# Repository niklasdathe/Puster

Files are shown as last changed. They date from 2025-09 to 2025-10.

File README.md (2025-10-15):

# Puster
## motivation  

I’ve been struggling with a light dust mite allergiy for years, so clean indoor air is more than just a comfort—it’s a necessity. Dust mites thrive in humid environments, and their microscopic waste is causing sneezing, itchy eyes and concentration problems. Since people spend over 90% of their time indoors, where pollutant concentrations can be two to five times higher than outdoors, the quality of indoor air has a huge influence on health (Morantes et al., *Environmental Science & Technology*, 2023; Sensirion, *Improving Indoor Air Quality*, 2023).  

Research shows that three pollutants—particulate matter most (PM2.5 and PM10), formaldehyde, and nitrogen dioxide—account for almost all of the chronic harm caused by typical indoor contaminants. Together they make up nearly 99% of the total health burden, with particulate matter alone responsible for more than 90% of the impact (Morantes et al., 2023). Poor indoor air quality is not only linked to allergies and asthma but also to reduced cognitive performance, sleep disruption, and higher risks of cardiovascular disease (Allen et al., *Environmental Health Perspectives*, 2015; Kang et al., *Building and Environment*, 2023).  

A standard HEPA filter like the one in Puster cannot remove everything, but it is very effective at capturing fine and coarse particles—including PM2.5, PM10, pollen, mold spores, and dust mite debris. This directly addresses the single most harmful category of indoor air pollutants. For the others, different strategies are needed:  

By focusing on HEPA particle filtration, Puster directly reduces the largest share of harm from indoor air pollution, while also lowering exposure to common allergens. Combined with sensible source control and optional add-ons like activated carbon, it offers a practical and flexible way to improve indoor air where it matters most.  

---

### what HEPA filters and what to add for the rest  

| Pollutant | Health effects | HEPA effective? | Remedies / add-ons |
|---|---|---|---|
| **PM2.5 / PM10** | Major cause of heart & lung disease, >90% of total harm. | ✅ Yes | Run HEPA Puster; boost during spikes (e.g., cooking, smoke); automate with Riecher. |
| **Pollen & dust mites** | Allergy & asthma triggers; mites thrive in humidity. | ✅ Yes | Keep RH ~40–60%; encase bedding; HEPA vacuuming. |
| **Mold spores** | Allergies, asthma, irritation. | ✅ Yes | Fix moisture issues; dehumidify; clean visible mold. |
| **NO₂** | Lung damage, asthma, heart risks. | ❌ No | Use induction/vented cooking; add carbon/chemisorbent filter. |
| **Formaldehyde** | Carcinogen, eye/lung irritant. | ❌ No | Avoid high-emitting materials. |
| **O₃** | Worsens asthma, lung irritation. | ❌ No | Avoid ozone devices; add carbon/MnO₂ media; ventilate when outdoor O₃ is low. |
| **VOCs** | Headaches, irritation; some are carcinogenic. | ❌ No | Source control + ventilation; thick carbon filter, replace often. |
| **Radon** | Second leading cause of lung cancer. | ❌ No | Building mitigation. |
| **CO₂** | Reduces cognition & sleep quality. | ❌ No | Ventilation; demand-control with CO₂ sensor (e.g., Riecher). |

---

**Key references for context:**  
- Morantes, G., Jones, B., Molina, C., & Sherman, M. H. (2023). *Harm from Residential Indoor Air Contaminants*. Environmental Science & Technology, 58(1), 242–257.  
- WHO Guideline for Formaldehyde: 0.1 mg/m³ (80 ppb) over 30 minutes.  
- Allen, J. G., et al. (2015). *Environmental Health Perspectives*. Cognitive decline with poor IAQ.  
- Kang, M., et al. (2023). *Building and Environment*. CO₂ impact on sleep quality.  
- Sensirion (2023). *Improving Indoor Air Quality* brochure.  

## mechanicals
### parts list
- **1x FY0194/30 (for phillips 800 series)**  
  widely available through many different sources 
- **1x ESP32C6 based PCB**  
  More infos/files can be found in /electronics/  
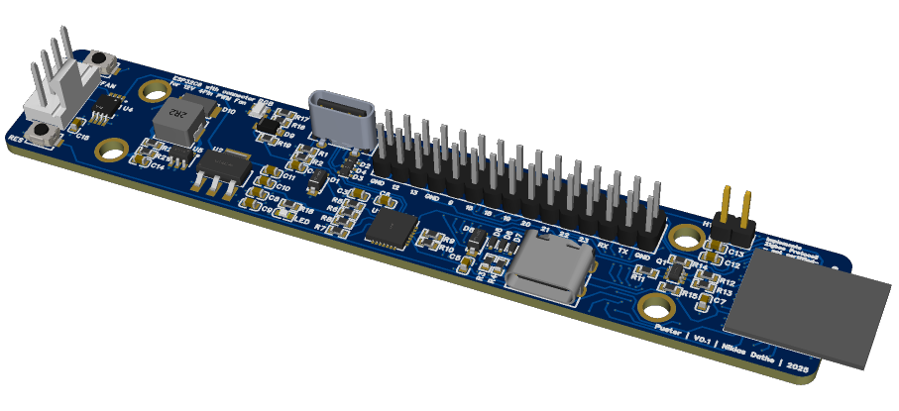
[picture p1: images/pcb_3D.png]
    
- **1x USB-C cable for powering the Puster**  
  this needs to be quite long as it acts as the power cable  
  also used to flash the firmware  
- **1x 4-Pin 12V PWM Fan**  
  i used a noctua fan as they are well built, quite and the color scheme suits my version of Puster  
- **1x base**  
  I routed mine out of reclaimed bankirai wood but you could also print this.  
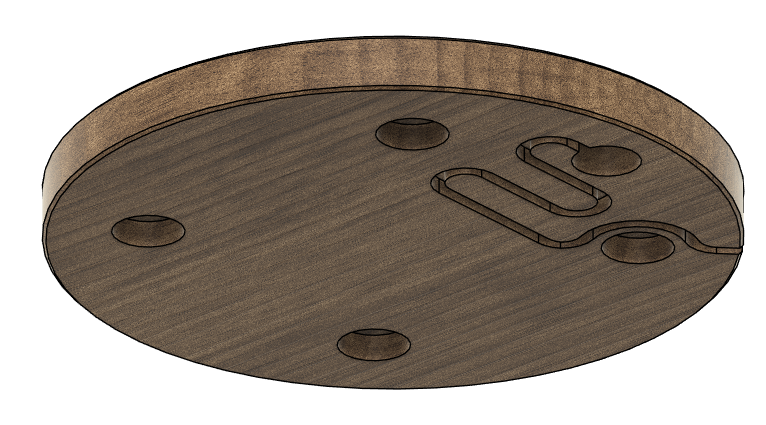
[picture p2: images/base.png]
    
- **1x lid**  
  3D printed out wood-filled-filament but you can use whatever filament you like. Feel free to get creative.:)  
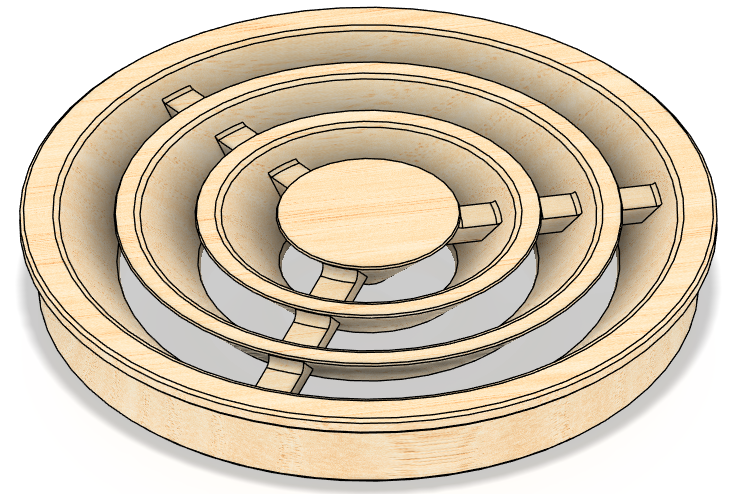
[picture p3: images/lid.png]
    
- **1x cage**  
  3D printed out wood-filled-filament but you can use whatever filament you like. Feel free to get creative.:)  
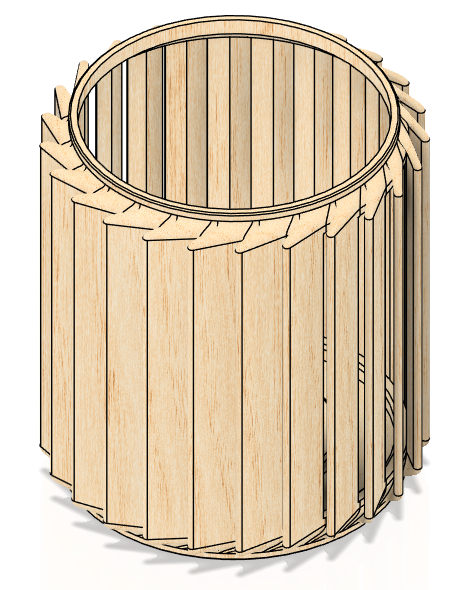
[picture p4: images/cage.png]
    
- **1x adapter**  
  3D printed out wood-filled-filament but you can use whatever filament you like. Feel free to get creative.:)  
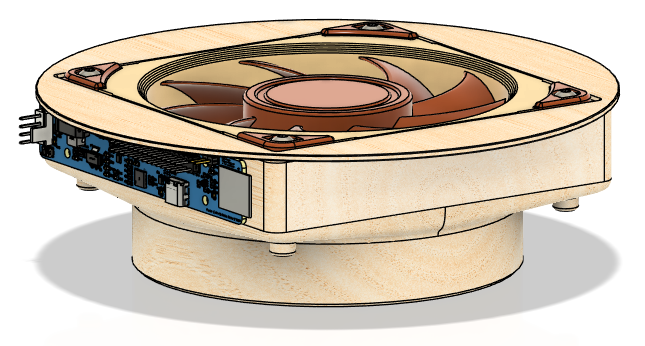
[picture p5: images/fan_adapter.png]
    
- **4x rubber feet**  
  these could easily be 3d printed but i used off the shelf parts i had laying around  
  [20mm diameter, 12mm height, 4mm thorugh hole]  
- _x screws
  TODO

### manufacturing

The ***base*** was routed from wood using a cnc machine. This was a dual sided operation as it has features on both sides of the base. On the bottom there is a place for the cable to be routed which acts as a strain relief at the same time. The base is attached to the cage with 4 M4 bolts that also hold the feet in place. I decided against the single responsiblilty idea for simplicity reasons.  
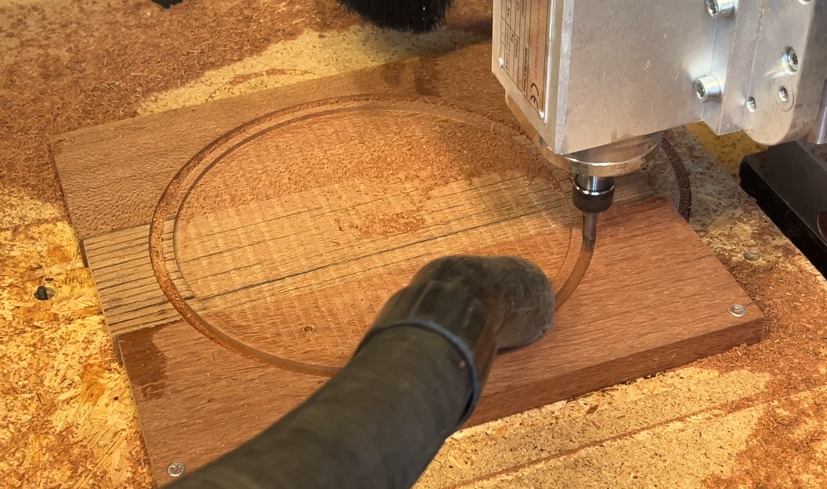
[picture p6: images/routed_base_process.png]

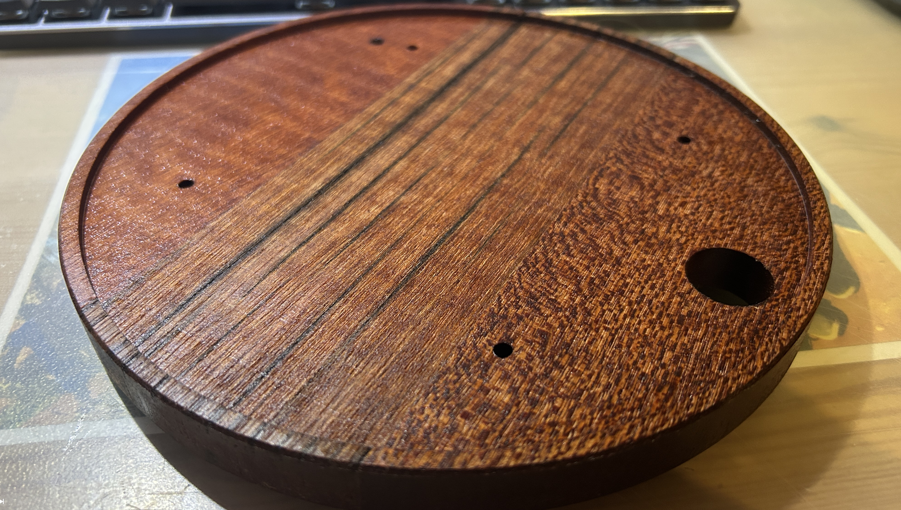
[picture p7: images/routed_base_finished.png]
  
The ***cage*** was printed with Bambu Labs wood filament. It just fits on my P1S. On the 0.3mm layer height preset with a 0.6mm nozzle, the print took 12 hours. On my usual preset it would've taken 41 hours.  

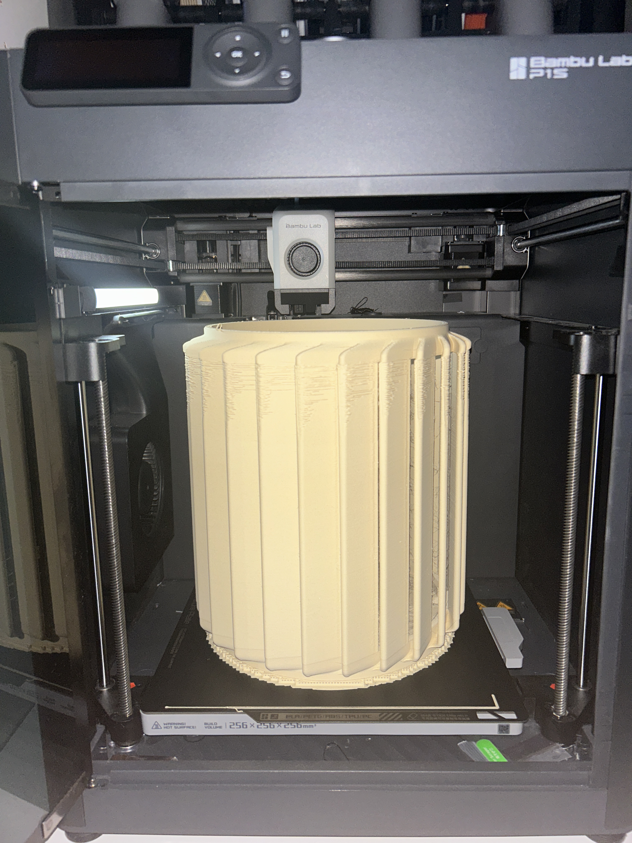
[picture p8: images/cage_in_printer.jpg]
  

On my version the print got quite a lot of defects near the top of the print which happended because the vertical slats were unsupported and flexing substantially due to the printing forces. This is mitigated in the current version by added cross braces. Also, the top opening was slightly too small which was also reworked in the second revision. 

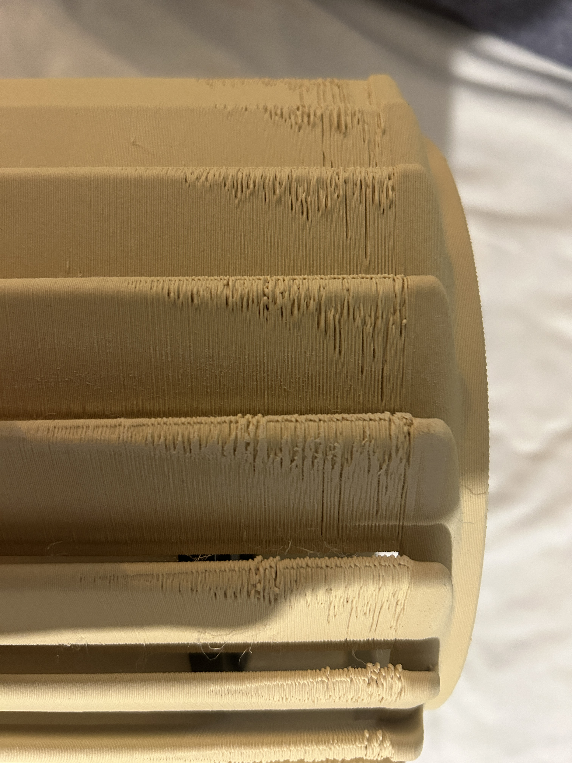
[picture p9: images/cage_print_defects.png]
  

The ***lid*** was also printed from the same filament. This took just 4 hours.

The ***adapter*** was also printed in this filament for consistency reasons. Here I didnt get around using support structures but with a well tuned preset, they were easily removed.

## electronics
### the pcb 
you can order the pcb through the following link:  
https://aisler.net/p/XLGCRZIT  
i added a stencil to help me with assembly.

the ESP32-C6 was chosen as the core of the Puster PCB because it offers modern wireless connectivity while staying flexible for different smart home ecosystems. with support for Wi-Fi 6, Bluetooth Low Energy 5.0, Zigbee and Thread (Matter), it can easily integrate into existing setups, whether that’s a Zigbee network, Matter-over-Thread, or simple Wi-Fi control. this makes the device adaptable for the future without locking it to one protocol.

for fan control, I used the EMC2101, a dedicated I²C fan controller. this chip simplifies reliable 4-pin PWM fan operation by:  

- generating the Intel-spec compliant PWM signal.
- monitoring the fan tachometer feedback for RPM validation.
- allowing precise control of fan speed directly over the I²C bus.

by offloading the fan PWM and tachometer handling to the EMC2101, the ESP32-C6 remains free for wireless communication and higher-level logic. this approach ensures smooth and safe operation of 12V PC-style fans without risking glitches or timing issues from software-driven PWM and tacho pulse counting.  

I also brought out the full GPIO Header known from the ESP32 Devkits which allows the Puster to be extended to your liking. 

routing turned out to be quite the challenge as the board is only 2cm wide but i managed to somehow squeeze it all in:  
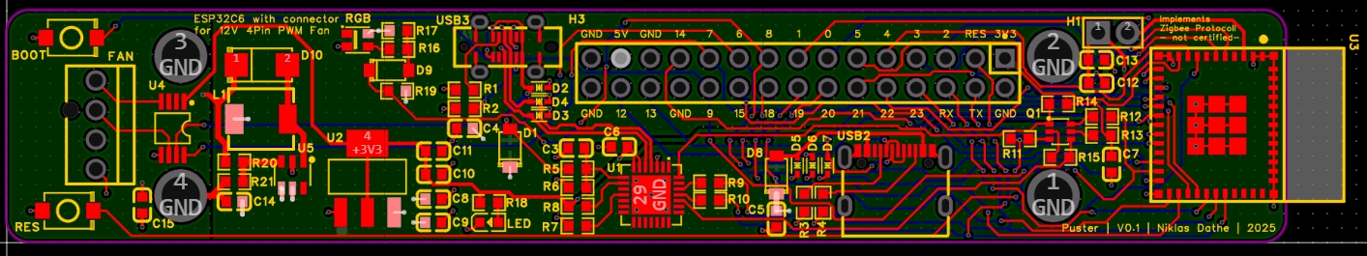
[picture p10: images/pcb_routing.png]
   
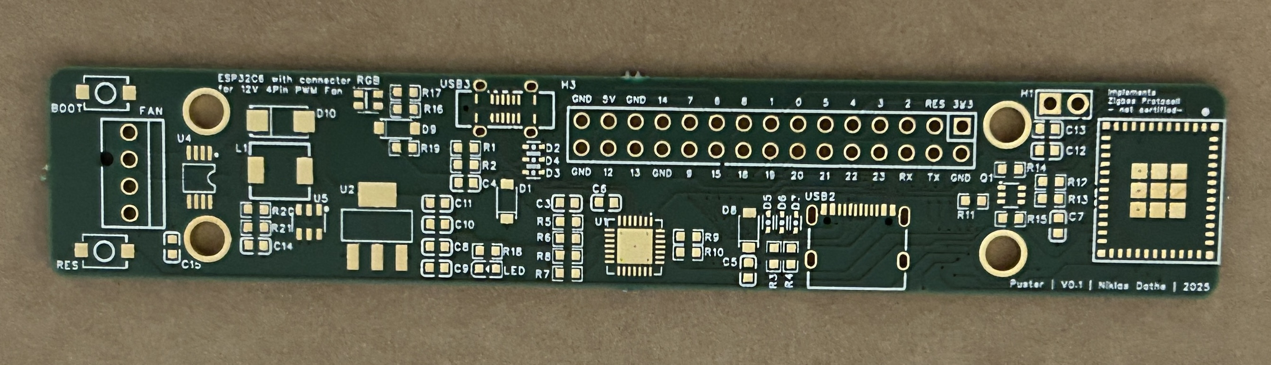
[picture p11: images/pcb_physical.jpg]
   
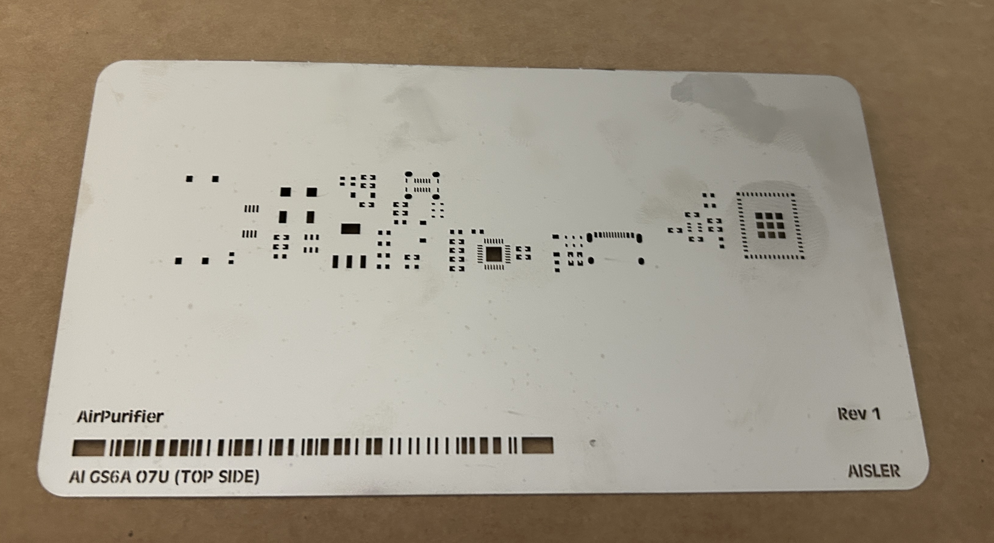
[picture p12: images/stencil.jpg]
   

### assembly 
TODO - pictures of my assembly process
### testing
TODO -pictures of pcb testing

### the fan
the pcb was built around this type of fan connector(TODO specific kind):  

(from Noctua PWM specifications 
white paper)

*Its important that only 12V fans are used, as other fans might get damaged by being overvolted.*

the pwm lines are driven at 5V, as per intel specification  

## software
## zigbee setup
With the current configuration this device acts as a zigbee router. THat means it will extend your zigbee mesh. I decided to this because I don't have tight power constraints as its plugged into the wall.   

   

the Zigbee data model is set up in a way, that the tachometer data (actual fan rpm) can be read from the device over Zigbee and the fan pmw (desired fan rpm) can be set over Zigbee. I haven't tried this yet but you might be able to close the control loop with this.  
TODO. actual cLuster/endpoint architecture

  

### why zigbee?
That decision was simple, i already had a working zigbee mesh network. I've been interested in Matter over Thread lately but thats a story for another time.

*im sure its easily adapted to matter over thread, wifi or whatever other radio protocolls your using in your smarthome*

### pairing
TODO

### resetting
TODO

### integration with homeassitant (zigbee2mqtt)
TODO

### flashing custom firmware
TODO - which port to use, links to implementation help/wikis
If anyone adapts this to other protocolls, feel free to share it so other people can benfit too

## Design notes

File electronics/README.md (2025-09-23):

This folder contains everything related to the PCB 

Link to the Aisler Project through which you can order the board:  
https://aisler.net/p/XLGCRZIT (you might want to order a stencil too, as I'm using 0603 components)

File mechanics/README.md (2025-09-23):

this folder contains all the files for the mechanical assembly

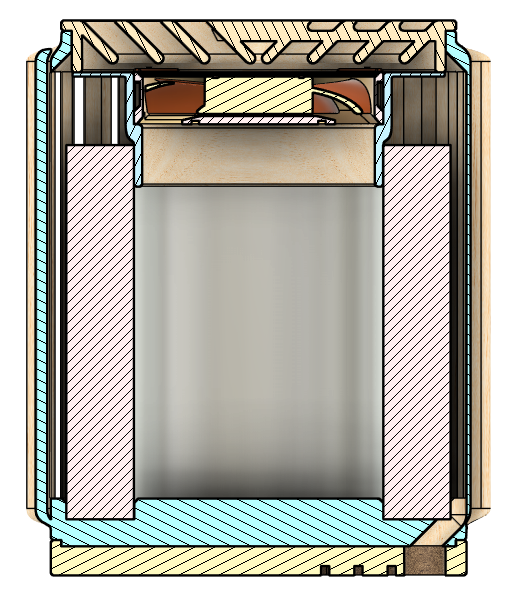
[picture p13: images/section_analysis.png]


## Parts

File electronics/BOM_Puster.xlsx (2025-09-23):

No. | Quantity | Comment | Designator | Footprint | Value | Manufacturer Part | Manufacturer | Supplier Part | Supplier | Add into BOM
1 | 2 | TS-1088-AR02016 | BOOT,RES | SW-SMD_L3.9-W3.0-P4.45 |  | TS-1088-AR02016 | XUNPU(讯普) | C720477 | LCSC | yes
2 | 1 | 1uF | C3 | C0603 | 1uF | CL10A105KB8NNNC | SAMSUNG(三星) | C15849 | LCSC | yes
3 | 8 | 10uF | C4,C5,C6,C8,C10,C12,C14,C15 | C0603 | 10uF | CL10A106MQ8NNNC | SAMSUNG(三星) | C1691 | LCSC | yes
4 | 1 | DNP | C7 | C0603 | 1uF | CL10A105KB8NNNC | SAMSUNG(三星) | C15849 | LCSC | yes
5 | 3 | 100nF | C9,C11,C13 | C0603 | 100nF | CC0603KRX7R9BB104 | YAGEO(国巨) | C14663 | LCSC | yes
6 | 2 | 1N5819HW-7-F | D1,D8 | SOD-123_L2.7-W1.6-LS3.7-RD |  | 1N5819HW-7-F | DIODES(美台) | C82544 | LCSC | yes
7 | 6 | LESD5D5.0CT1G | D2,D3,D4,D5,D6,D7 | SOD-523_L1.2-W0.8-LS1.6-BI |  | LESD5D5.0CT1G | UMW(友台半导体) | C5199850 | LCSC | yes
8 | 1 | 1N4148W | D9 | SOD-123_L2.8-W1.8-LS3.7-RD-1 |  | 1N4148W | JSMSEMI(杰盛微) | C917030 | LCSC | yes
9 | 1 | SS34 | D10 | SMA_L4.3-W2.6-LS5.2-RD |  | SS34 | MDD(辰达半导体) | C8678 | LCSC | yes
10 | 1 | 470531000 | FAN | CONN-TH_47053-1000 |  | 470531000 | MOLEX | C240840 | LCSC | yes
11 | 1 | Jumper-2.54mm | H1 | HDR-TH_2P-P2.54-V-M |  | Jumper-2.54mm | XFCN(兴飞) | C492401 | LCSC | yes
12 | 1 | 15x2-2.54mm | H3 | HDR-TH_30P-P2.54-V-M-R2-C15-S2.54-BL |  | 15x2-2.54mm | XKB Connection(中国星坤) | C725887 | LCSC | yes
13 | 1 | 22uH | L1 | IND-SMD_L5.5-W5.2 | 22uH | SMMS0530-220M | SXN(顺翔诺) | C2842153 | LCSC | yes
14 | 1 | KT-0603R | LED | LED0603-RD |  | KT-0603R | KENTO | C2286 | LCSC | yes
15 | 1 | BC847BDW1T1G | Q1 | SOT-363_L2.0-W1.3-P0.65-LS2.1-TL |  | BC847BDW1T1G | onsemi(安森美) | C82368 | LCSC | yes
16 | 5 | 5.1kΩ | R1,R2,R3,R4,R18 | R0603 | 5.1kΩ | 0603WAF5101T5E | UNI-ROYAL(厚声) | C23186 | LCSC | yes
17 | 1 | 22.1kΩ | R5 | R0603 | 22.1kΩ | 0603WAF2212T5E | UNI-ROYAL(厚声) | C25961 | LCSC | yes
18 | 1 | 47.5kΩ | R6 | R0603 | 47.5kΩ | 0603WAF4752T5E | UNI-ROYAL(厚声) | C23061 | LCSC | yes
19 | 4 | 10kΩ | R7,R14,R15,R17 | R0603 | 10kΩ | 0603WAF1002T5E | UNI-ROYAL(厚声) | C25804 | LCSC | yes
20 | 1 | 1kΩ | R8 | R0603 | 1kΩ | 0603WAF1001T5E | UNI-ROYAL(厚声) | C21190 | LCSC | yes
21 | 6 | 0Ω | R9,R10,R11,R12,R13,R16 | R0603 | 0Ω | 0603WAF0000T5E | UNI-ROYAL(厚声) | C21189 | LCSC | yes
22 | 2 | 3.3kΩ | R19,R21 | R0603 | 3.3kΩ | 0603WAF3301T5E | UNI-ROYAL(厚声) | C22978 | LCSC | yes
23 | 1 | 62kΩ | R20 | R0603 | 62kΩ | FRC0603F6202TS | FOJAN(富捷) | C2907059 | LCSC | yes
24 | 1 | WS2812B-2020 | RGB | LED-SMD_4P-L2.0-W2.0-TL_WS2812B-2020 |  | WS2812B-2020 | worldsemi | C965555 | LCSC | yes
25 | 1 | CP2102N-A02-GQFN28R | U1 | QFN-28_L5.0-W5.0-P0.50-TL-EP3.3 |  | CP2102N-A02-GQFN28R | SKYWORKS/SILICON LABS(芯科) | C964632 | LCSC | yes
26 | 1 | SGM2212-3.3XKC3G/TR | U2 | SOT-223-3_L6.5-W3.4-P2.30-LS7.0-BR |  | SGM2212-3.3XKC3G/TR | SGMICRO(圣邦微) | C3294699 | LCSC | yes
27 | 1 | ESP32-C6-MINI-1-N4 | U3 | WIFIM-SMD_61P-L16.6-W13.2-P0.80-ESP32-C6-MINI-1-N4 |  | ESP32-C6-MINI-1-N4 | ESPRESSIF(乐鑫) | C5736265 | LCSC | yes
28 | 1 | EMC2101-ACZL-TR | U4 | MSOP-8_L3.0-W3.0-P0.65-LS4.9-BL |  | EMC2101-ACZL-TR | MICROCHIP(美国微芯) | C626967 | LCSC | yes
29 | 1 | MT3608 | U5 | SOT-23-6_L2.9-W1.6-P0.95-LS2.8-BL |  | MT3608 | 西安航天民芯 | C84817 | LCSC | yes
30 | 1 | TYPE-C 16PIN 2MD(073) | USB2 | USB-C-SMD_TYPE-C-6PIN-2MD-073 |  | TYPE-C 16PIN 2MD(073) | SHOU HAN(首韩) | C2765186 | LCSC | yes
31 | 1 | TYPEC-303-ACP16 | USB3 | USB-C-SMD_TYPEC-303-ACP16 |  | TYPEC-303-ACP16 | XUNPU(讯普) | C720628 | LCSC | yes

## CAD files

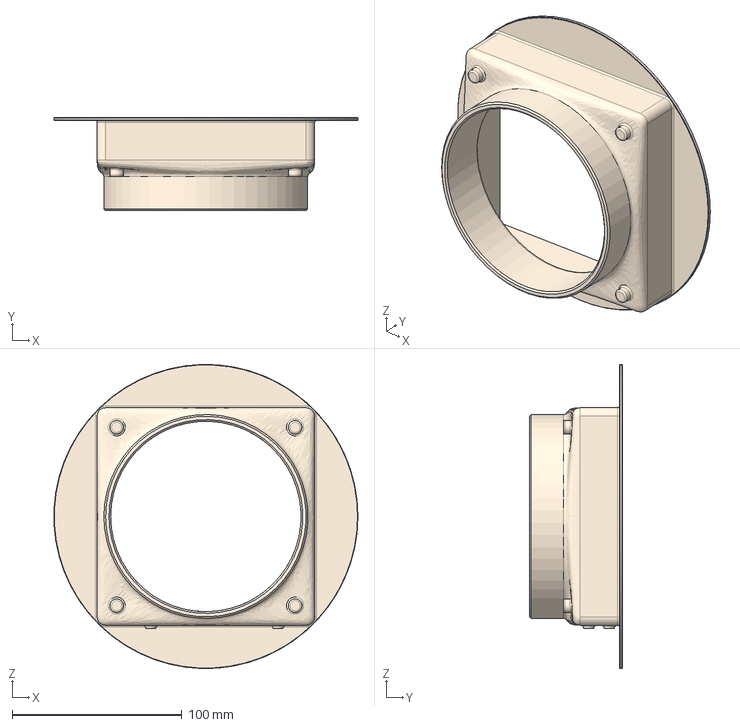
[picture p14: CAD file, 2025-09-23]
mechanics/fan_adapter.step
178.9 x 55.0 x 178.9 mm

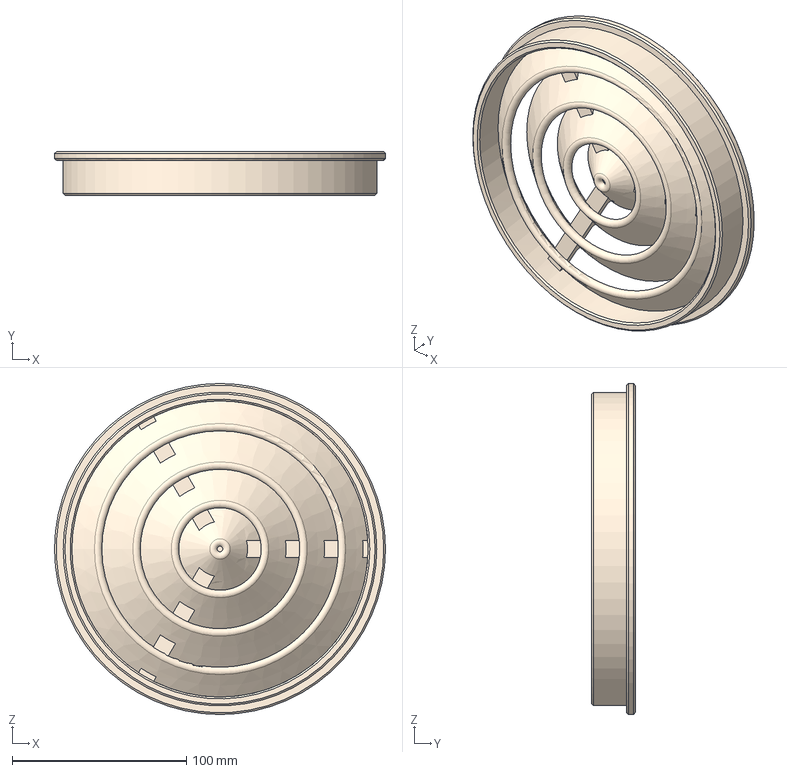
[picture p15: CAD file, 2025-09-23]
mechanics/lid.step
190.0 x 25.0 x 190.0 mm

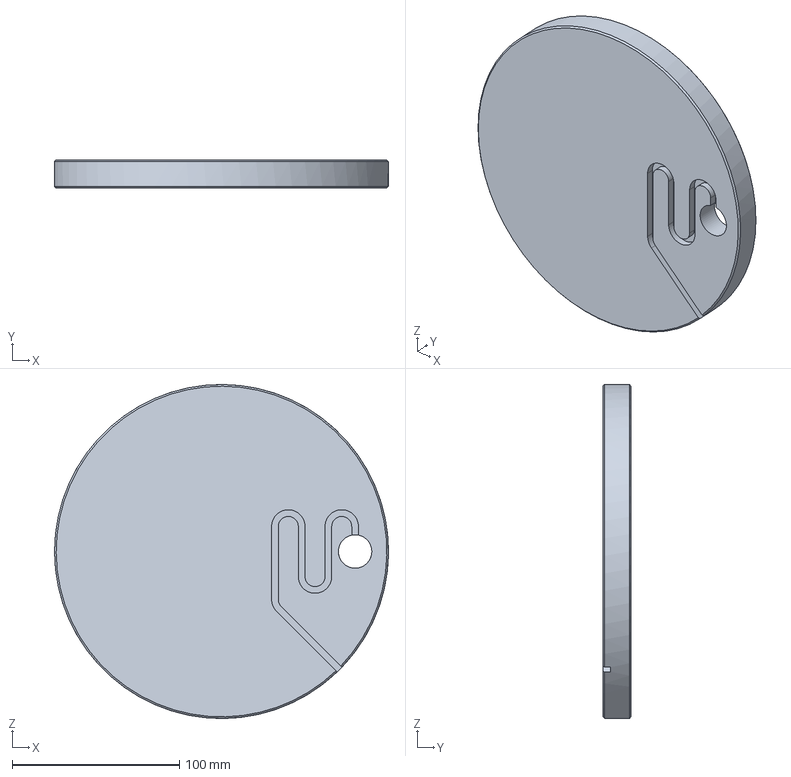
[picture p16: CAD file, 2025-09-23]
mechanics/base.step
200.0 x 17.0 x 200.0 mm

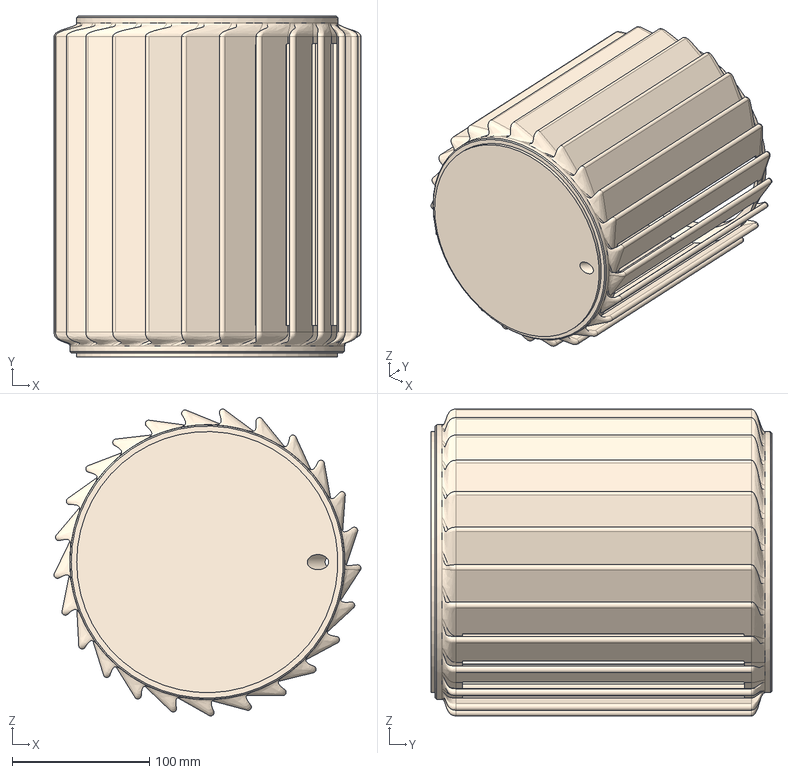
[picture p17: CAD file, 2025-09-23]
mechanics/cage.step
223.4 x 248.0 x 223.3 mm

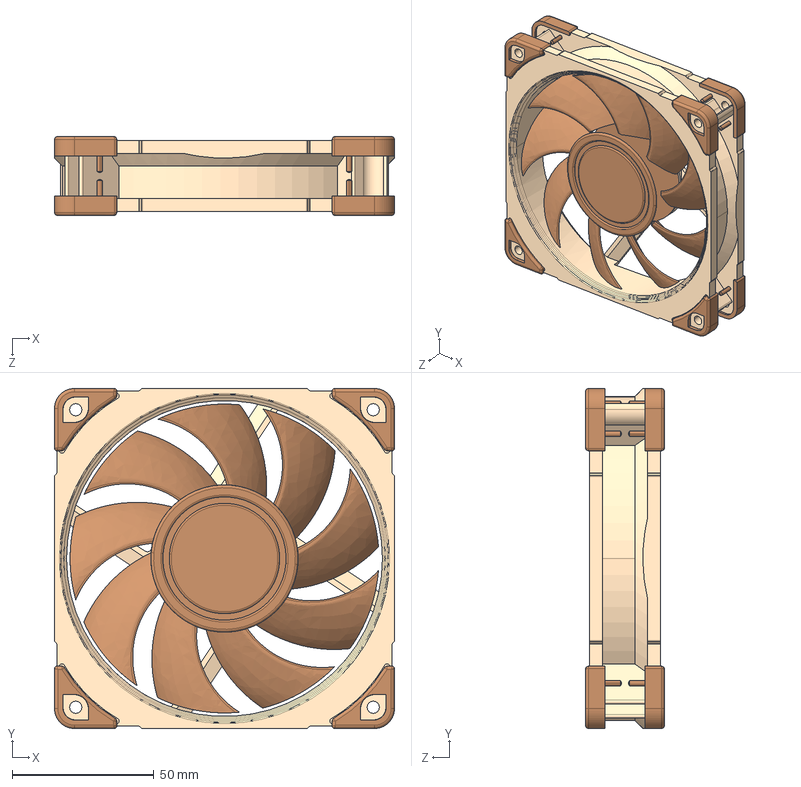
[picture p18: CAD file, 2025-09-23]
mechanics/NF_A12x25_stp.STEP
120.0 x 120.0 x 28.0 mm
Frame
Fan
Damper x 8

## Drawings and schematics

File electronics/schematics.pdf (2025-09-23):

IO21 27 IO22 28 IO23 29 RXD0 30 TXD0 31 NC 32 NC 33 NC 34 NC 35 GND 36 GND 37 GND 38 GND 39 GND 40 GND 41 GND 42 GND 43 GND 44 GND 45 GND 46 GND 47 GND 48 GND 49 GND 50 GND 51 GND 52 GND 53

# +3V3C¹² 10uF

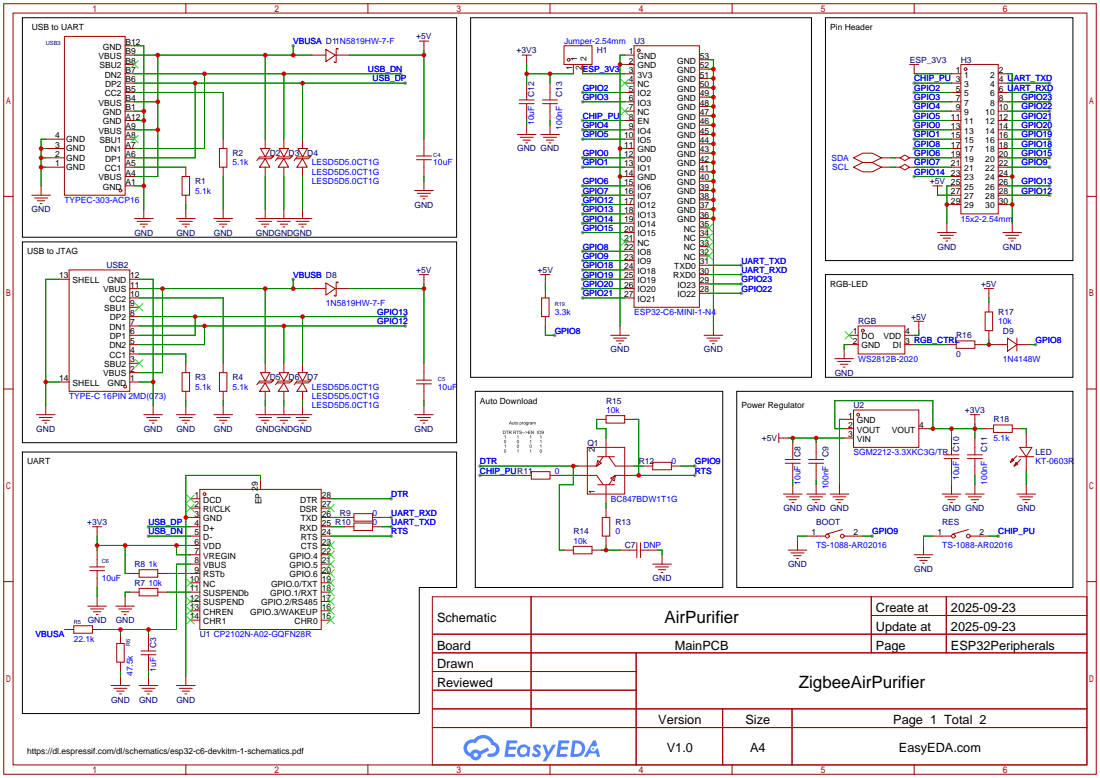
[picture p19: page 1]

USB to UART
GND A1 VBUS A4 CC1 A5 DP1 A6 DN1 A7 SBU1 A8 VBUS A9 GND A12 GND B1 VBUS B4 CC2 B5 DP2 B6 DN2 B7 SBU2 B8 VBUS B9 GND B12

Schematic | AirPurifier | Create at | 2025-09-23

Update at | 2025-09-23

Board | MainPCB | Page | ESP32Peripherals
Drawn | | ZigbeeAirPurifier
Reviewed

Version | Size | Page 1 Total 2
V1.0 | A4 | EasyEDA.com

https://dl.espressif.com/dl/schematics/esp32-c6-devkitm-1-schematics.pdf

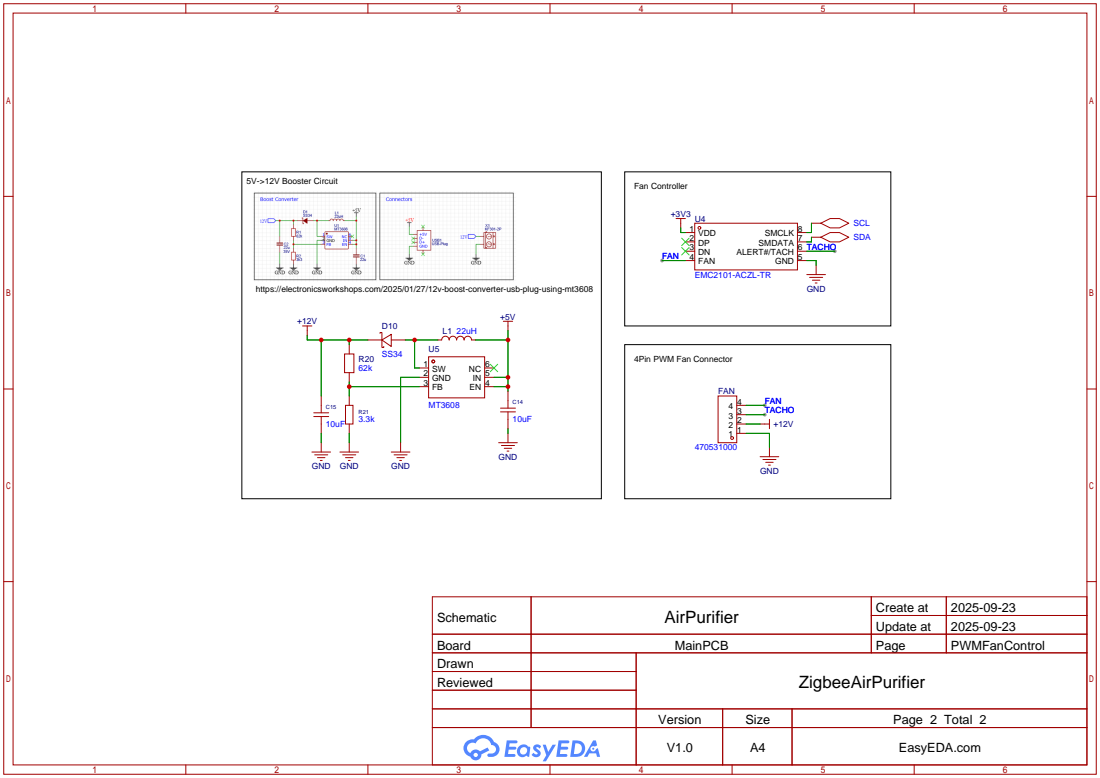
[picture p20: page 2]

Fan Controller 5V->12V Booster Circuit

https://electronicsworkshops.com/2025/01/27/12v-boost-converter-usb-plug-using-mt3608

Schematic | AirPurifier | Create at | 2025-09-23

Update at | 2025-09-23

Board | MainPCB | Page | PWMFanControl
Drawn | | ZigbeeAirPurifier
Reviewed

Version | Size | Page 2 Total 2
V1.0 | A4 | EasyEDA.com

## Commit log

2025-09-23 Update README with parts list and fan details
    Added parts list and fan specifications to README.
2025-09-23 Enhance README with motivation and software sections
    Added sections on motivation, software, and fan details.
2025-09-23 Update README with Aisler Project link
    Added links to the Aisler Project for ordering PCBs.
2025-09-23 Update README with Zigbee network information
    Added a note about the existing Zigbee mesh network and interest in Matter over Thread.
2025-09-23 Update README with routing challenges and fan details
    Corrected formatting and added details about PCB routing challenges and fan specifications.
2025-09-25 Enhance README with detailed air quality information
    Expanded the motivation section to emphasize the importance of clean indoor air and its health impacts. Added detailed information on pollutants and their effects, along with a table summarizing HEPA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
2025-10-04 Revise README for clarity on air quality and HEPA filters
    Corrected spelling and clarified health effects related to dust mite allergies. Updated HEPA filter effectiveness details and remedies for various pollutants.
2025-10-15 Revise cage and adapter details in README
    Updated print times and issues for cage and adapter.
2025-10-15 Update image reference and print defect details
    Updated image reference in README and added details about print defects and improvements.
2025-10-15 Add images for PCB routing and assembly
    Added images to enhance documentation and provide visual references.
2025-10-15 Replace PCB and stencil images with JPG versions
    Updated image references in README for physical PCB and stencil.
